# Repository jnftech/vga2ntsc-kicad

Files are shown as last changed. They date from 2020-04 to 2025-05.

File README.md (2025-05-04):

# RetroTINK VGA2NTSC - KiCad Conversion/Modification

This is a modified version of Mike Chi's VGA2NTSC v1.1.
The first goal was to convert the original Altium source files to KiCad - a free and open source tool - as not everyone has access to Altium. Secondly, most footprints have been swapped to make the board more DIY friendly - for example swapping 0402 components (difficult to solder by hand) with 0805 or larger.

As of April 2023, the version shown here is a "final" version (meaning I will no longer make further improvements) that I completed in mid-2021 and only now finally publishing to Github. The changes between the Old version (2020/04/20, archived in the "_Old" folder) and this version are outlined below. 

<p align="center">
  
  
</p>

### Goals:
- Convert original Altium project to KiCad
- Use 0805 footprints instead of smaller packages
- Keep location of jacks and mounting holes in the same locations
- Keep circuit identical to original schematics
- Adjust vertical board size slightly to fit within 100x100mm size limit for cheap boards with many popular PCB fabs
- Add a footprint for a DC barrel jack instead of USB power (either-or can be used in the same spot). Warning has been added to the board denoting 5V power only
- Modified power distribution rail using bottom layer of board
- Relocated clock section to minimize routing near other signals or underneath video amp
- Minimized the use of vias for signal traces where possible.
- More KiCad practice for me
- Finally try to publish something on GitHub (first repo!)

### Changed from 2020/04/20 version:
- Tided up board outline and removed some workaround circular holes in some footprints.
- Added selectable HV/CSYNC switch
- AC coupling on the RGB lines of Scart Output (C22 - C25). The original design left these DC coupled. DC coupling can still be achieved by simply jumping the capacitor pads (for example using larger 0 ohm resistors, like 1206 or 1812)
- There are a few extra "tinkerer/advanced" pins (see below) but there are two solder jumpers implemented to make use of these.

### TL;DR on the two solder jumpers (JP1 and JP2)
- Close these both with solder if you want just NTSC video output. If you are not sure, then just close them both.

### Advanced/Tinkerer features (ignore this if you want just NTSC output with the standard board setup)
- Added a way to bypass the on-board clock circuit. This might be handy for someone wanting to get PAL output from the board by feeding in an external clock signal (EXT_CLOCK). See warning note below.
  - Note that JP1 must be closed with solder for "normal" NTSC operation using the onboard clock circuit. Leave JP1 open to feed external clock signal.
- Added pads for manipulating the NTSC/PAL pin on the AD725 if desired. Switching to PAL would require a different clock signal (see above, and see warning note below).
  - Close JP2 with solder for "normal" NTSC operation. (Just pulls the AD's STND pin high)
  - Leave JP2 open if you want the ability to toggle the mode.
  - WARNING: The three pins in the middle of the board (labeled "NTSC", "", and "PAL" on the underside) are there to implement a toggle. However the "NTSC" and "PAL" pins are just VCC and GND respectively, with the center pin being connected to the AD725's STND pin (which must be pulled either HIGH for NTSC, or LOW for PAL). As I did not have the foresight to think that through, there are no pullup/pulldown resistors. In other words DO NOT SHORT THE NTSC AND PAL PINS TOGETHER, and dont use MBB-style switches to toggle between.
- Added a YTRAP pad for feeding an external YTRAP circuit to the AD725.

### Notes:

<span style="color: red;">This board and circuit, as depicted in this repository, will only deliver an NTSC signal (hence the name VGA2NTSC).
Presence of the aforementioned extra pins (jumpers, clock and NTSC/PAL pins) do not indicate that this board natively supports PAL or any standard other than NTSC.
Those options are for advanced users/tinkerers that are prepard to supply the appropriate clock signal to the board to support other standards.</span>

The board design uses vias-in-pads. This can be a problem for some fabs. JLCPCB (at least with default HASL plating) and OSHpark dont seem to have an issue with this, but some fabs might depending on how they plate the pads. You may need to adjust the locations of the vias and add a couple traces to compensate, should you run into this situation.

### Tools used for conversion:
- Altium2Kicad https://github.com/thesourcerer8/altium2kicad
- Tracespace View (conversion of original Gerbers to SVG for reference and silkscreen adaptations - Alitum2Kicad doesn’t translate original fonts/graphics) https://tracespace.io/view/
- KiCad 5.1.8 https://www.kicad.org/
- Inkscape https://inkscape.org/

<p align="center">
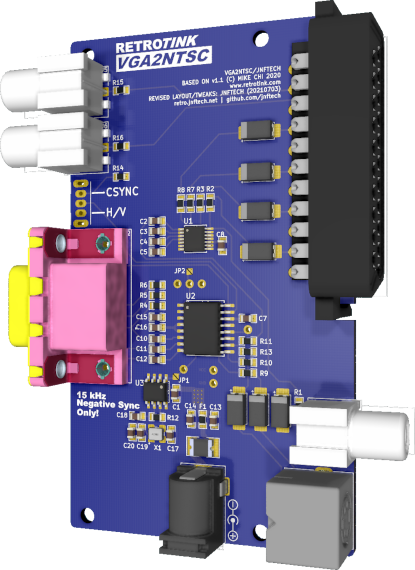
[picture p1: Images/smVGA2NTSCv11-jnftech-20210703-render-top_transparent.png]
<br />
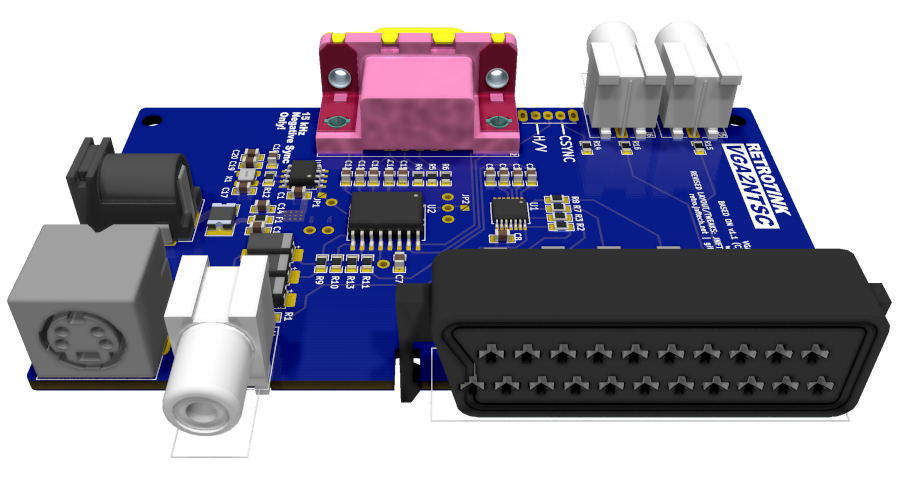
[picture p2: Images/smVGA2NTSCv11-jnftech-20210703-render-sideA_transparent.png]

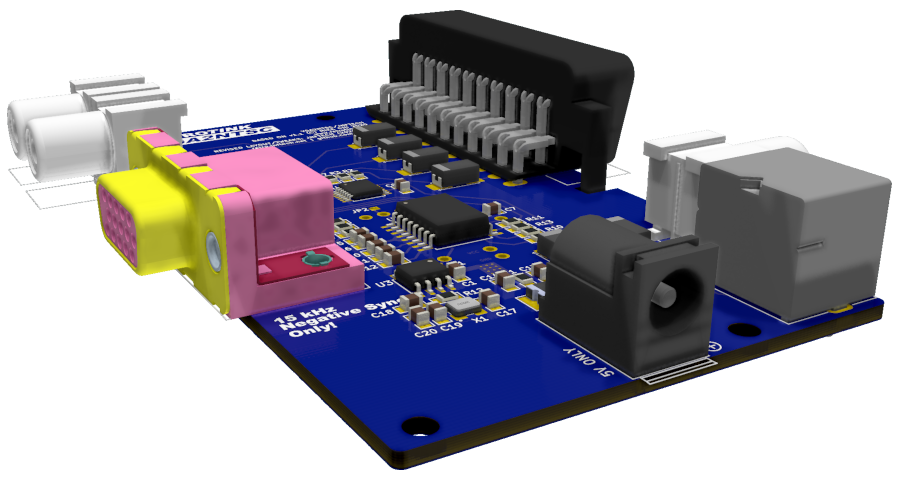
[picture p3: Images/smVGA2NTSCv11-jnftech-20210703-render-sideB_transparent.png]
<br />
</p>

This derivative work maintains the same source license as the original board.
https://www.retrotink.com/post/vga2ntsc-released

### “Mike Chi” License:
(From https://www.retrotink.com/post/vga2ntsc-released)

```
License
The materials are released under the terms below. I don't have time for pedantic nonsense or legal theory and like to keep things simple. I call this the 'Mike Chi' license.

- For each project, at my sole discretion, I may release whatever sources, to whatever level of abstraction, that I deem appropriate. Additional information/materials may be released on a scheduled determined at my sole discretion.
- You may modify, use or adapt any or all portions of the released material for any purpose you wish, including sale.
- The exception is that the files may not be used for commercial activities by entities, determined at my sole discretion, that have a history of violating intellectual property rights or licenses.
- If these materials were helpful and/or of use to you, I only ask that you provide some form of acknowledgment that you feel is fair.
- I'd also love to hear about how you're using it!
- If you re-distribute the material in a substantially unaltered form, please include this notice.
- NO WARRANTY EXPRESSED OR IMPLIED. WE TAKE ABSOLUTELY NO RESPONSIBILITY FOR WHAT MAY OCCUR FROM USAGE OF THE FILES.
- WE CANNOT AND WILL NOT OFFER ANY SUPPORT FOR THE USAGE OF THE FILES. IF YOU DO NOT AGREE WITH THESE TERMS THEN DO NOT USE ANY OF THE MATERIALS AND DON'T COMPLAIN.
```

https://www.retrotink.com/

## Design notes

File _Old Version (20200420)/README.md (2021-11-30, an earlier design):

# RetroTINK VGA2NTSC - KiCad Conversion/Modification

This is a modified version of Mike Chi's VGA2NTSC v1.1.
The first goal was to convert the original Altium source files to KiCad - a free and open source tool - as not everyone has access to Altium. Secondly, most footprints have been swapped to make the board more DIY friendly - for example swapping 0402 components (difficult to solder by hand) with 0805 or larger.

<p align="center">
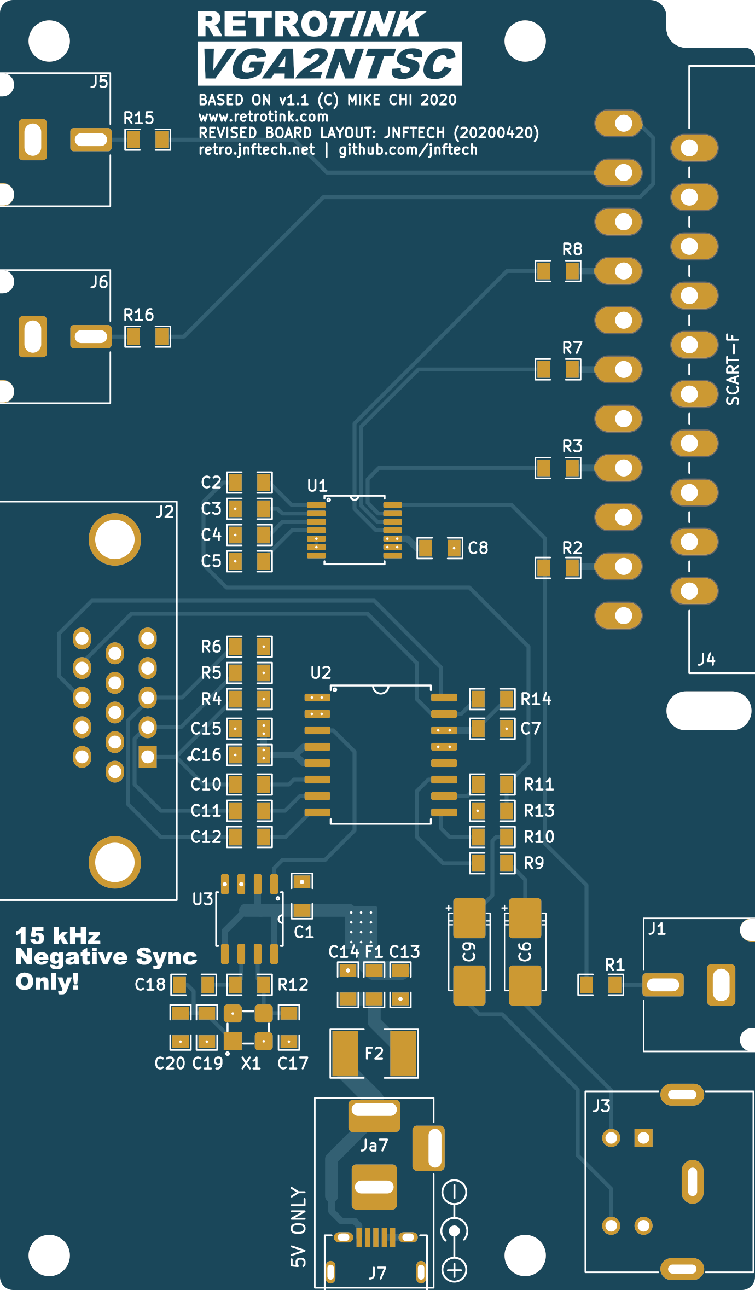
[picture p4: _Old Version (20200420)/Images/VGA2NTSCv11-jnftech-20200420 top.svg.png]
  
</p>

### Goals:
- Convert original Altium project to KiCad
- Use 0805 footprints instead of smaller packages
- Keep location of jacks and mounting holes in the same locations
- Keep circuit identical to original schematics
- Adjust vertical board size slightly to fit within 100x100mm size limit for cheap boards with many popular PCB fabs
- Add a footprint for a DC barrel jack instead of USB power (either-or can be used in the same spot). Warning has been added to the board denoting 5V power only
- Modified power distribution rail using bottom layer of board
- Relocated clock section to minimize routing near other signals or underneath video amp
- Minimized the use of vias for signal traces where possible.
- More KiCad practice for me
- Finally try to publish something on GitHub (first repo!)

### Todo:
- Tidy up board outline. Kicad doesnt play well with Edge.Cuts in footprints when they overlap the board outline, so the circular drills used on the SCART and RCJ-4xx footprints are a workaround.
- Add selectable HV/CSYNC switch
- Add additional clock circuit and switch for PAL mode
- Look for other improvements based on AD725 datasheet information
- (Maybe) version with SCART and/or XRGB-style 8-pin MiniDIN Input  
  
Some of these tweaks are on a test version that is being fabbed by JLCPCB now.

### Notes:
- The board design uses vias-in-pads. This can be a problem for some fabs. JLCPCB (at least with default HASL plating) and OSHpark dont seem to have an issue with this, but some fabs might depending on how they plate the pads. You may need to adjust the locations of the vias and add a couple traces to compensate, should you run into this situation.

### Tools used for conversion:
- Altium2Kicad https://github.com/thesourcerer8/altium2kicad
- Tracespace View (conversion of original Gerbers to SVG for reference and silkscreen adaptations - Alitum2Kicad doesn’t translate original fonts/graphics) https://tracespace.io/view/
- KiCad 5.1.5 https://www.kicad.org/
- Inkscape https://inkscape.org/

<p align="center">
<br />
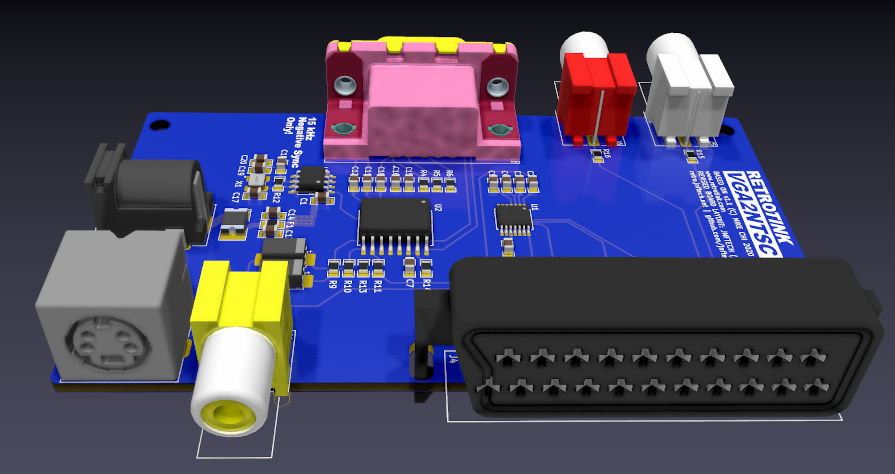
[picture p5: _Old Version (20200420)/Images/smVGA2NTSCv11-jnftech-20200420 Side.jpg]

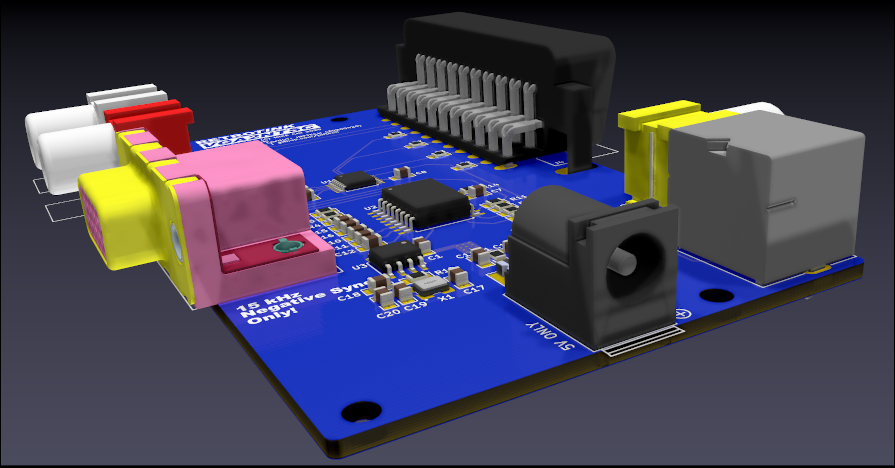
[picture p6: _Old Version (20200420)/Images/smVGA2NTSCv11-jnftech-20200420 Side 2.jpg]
<br />
</p>

This derivative work maintains the same source license as the original board.
https://www.retrotink.com/post/vga2ntsc-released

### “Mike Chi” License:
(From https://www.retrotink.com/post/vga2ntsc-released)

```
License
The materials are released under the terms below. I don't have time for pedantic nonsense or legal theory and like to keep things simple. I call this the 'Mike Chi' license.

- For each project, at my sole discretion, I may release whatever sources, to whatever level of abstraction, that I deem appropriate. Additional information/materials may be released on a scheduled determined at my sole discretion.
- You may modify, use or adapt any or all portions of the released material for any purpose you wish, including sale.
- The exception is that the files may not be used for commercial activities by entities, determined at my sole discretion, that have a history of violating intellectual property rights or licenses.
- If these materials were helpful and/or of use to you, I only ask that you provide some form of acknowledgment that you feel is fair.
- I'd also love to hear about how you're using it!
- If you re-distribute the material in a substantially unaltered form, please include this notice.
- NO WARRANTY EXPRESSED OR IMPLIED. WE TAKE ABSOLUTELY NO RESPONSIBILITY FOR WHAT MAY OCCUR FROM USAGE OF THE FILES.
- WE CANNOT AND WILL NOT OFFER ANY SUPPORT FOR THE USAGE OF THE FILES. IF YOU DO NOT AGREE WITH THESE TERMS THEN DO NOT USE ANY OF THE MATERIALS AND DON'T COMPLAIN.
```

https://www.retrotink.com/

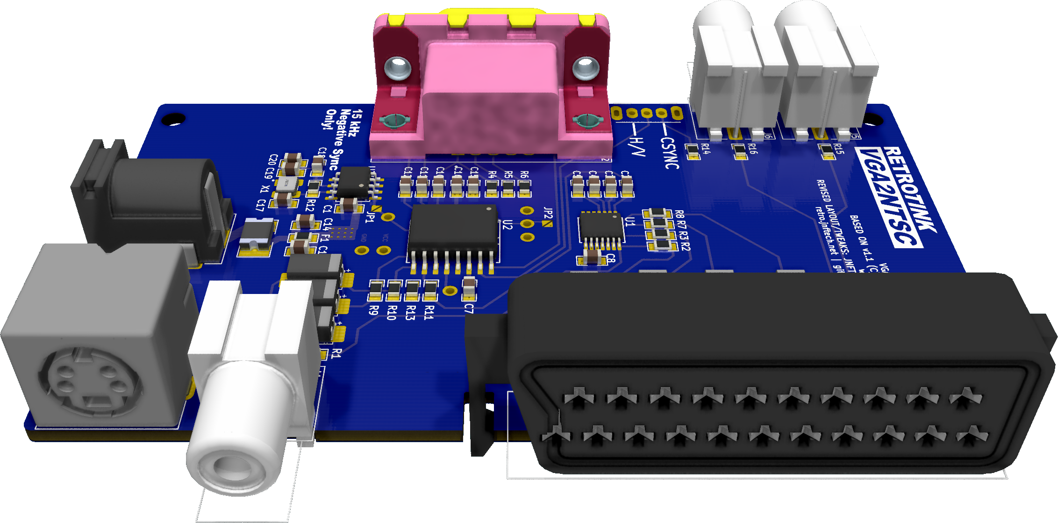
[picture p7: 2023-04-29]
Images/VGA2NTSCv11-jnftech-20210703-render-sideA_transparent.png

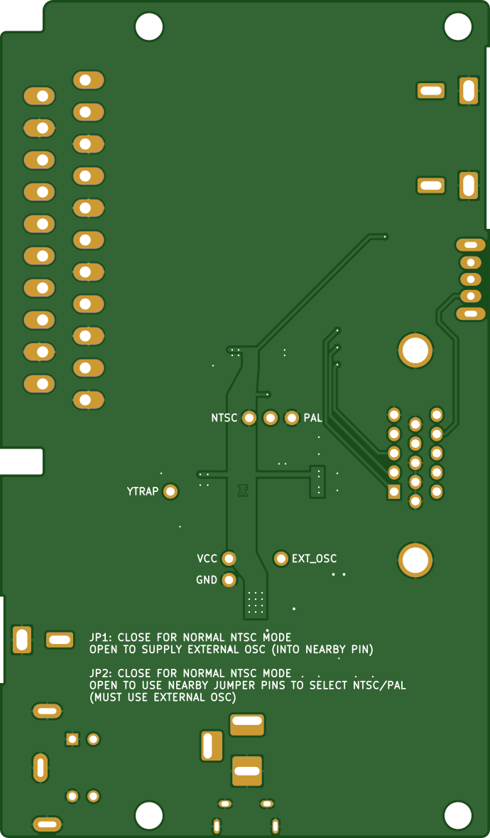
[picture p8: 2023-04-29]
Images/VGA2NTSCv11-jnftech-20210703-gerber-bottom.png

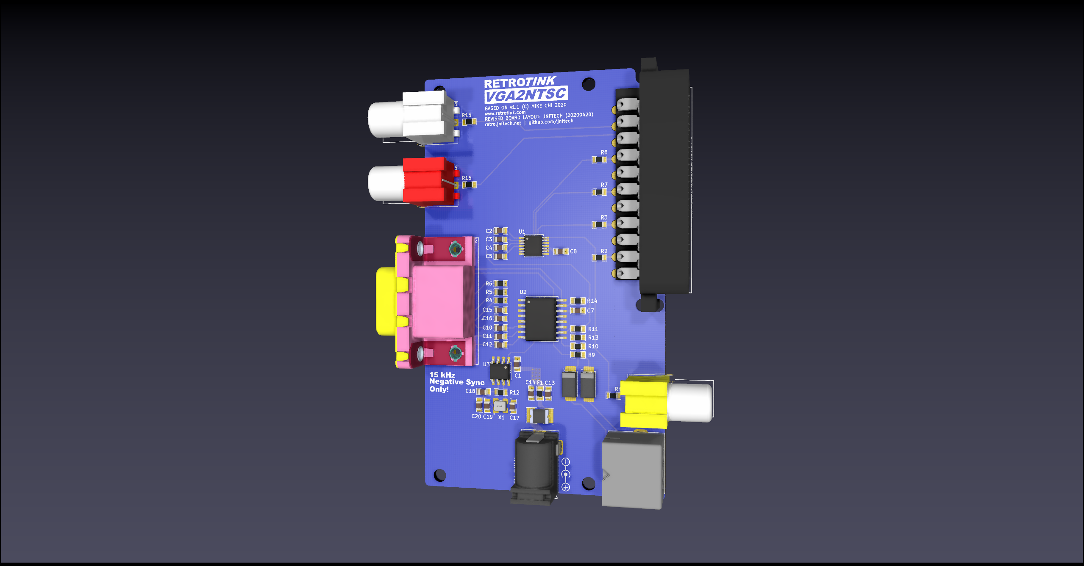
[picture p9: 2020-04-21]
Images/VGA2NTSCv11-jnftech-20200420 Top.png

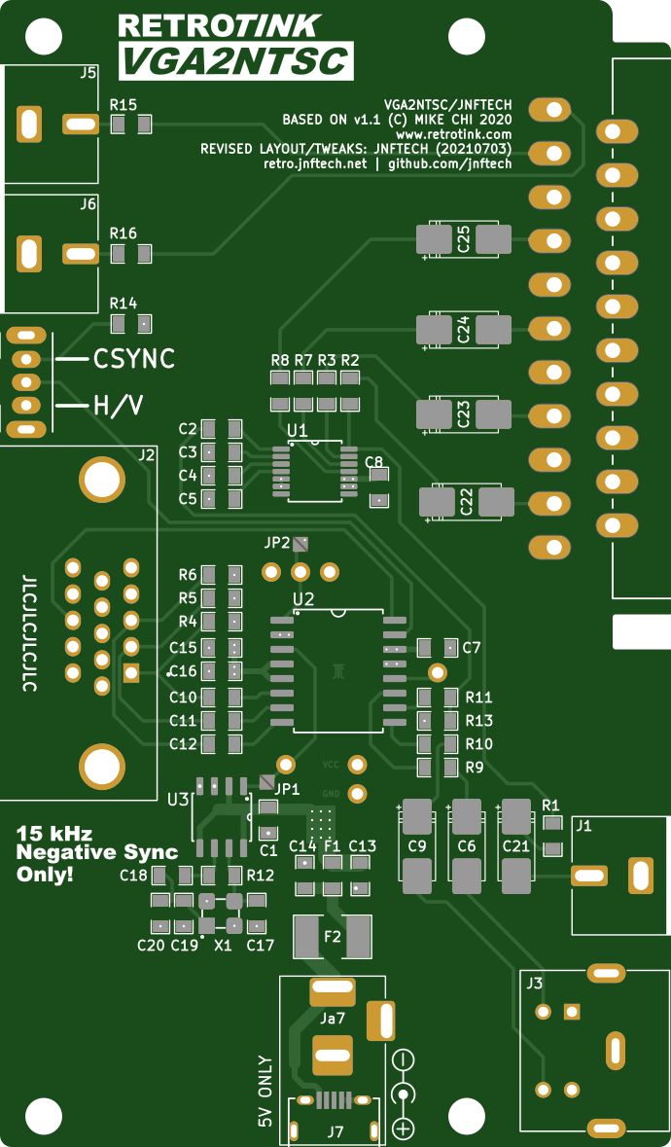
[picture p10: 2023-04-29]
Images/VGA2NTSCv11-jnftech-20210703-gerber-top.png

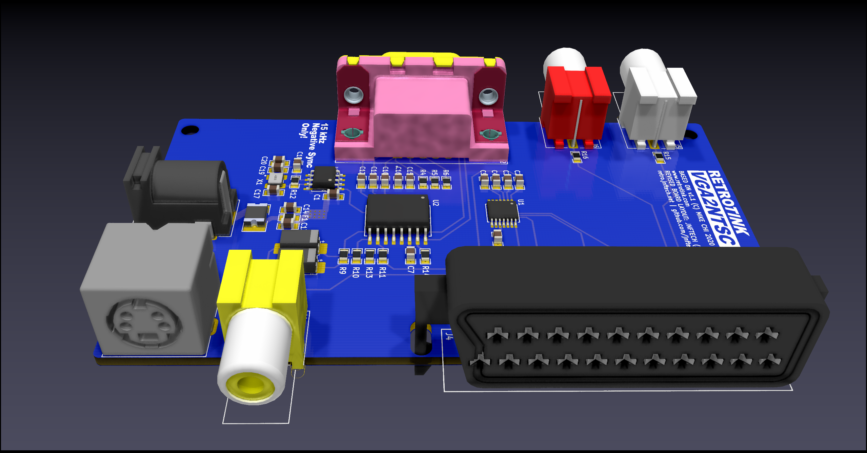
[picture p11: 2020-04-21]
Images/VGA2NTSCv11-jnftech-20200420 Side.png

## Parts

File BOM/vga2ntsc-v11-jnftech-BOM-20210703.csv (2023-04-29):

Designator | ManufacturerPartNumber | DigiKey | LCSC | Quantity | Value | Size | Voltage | Tolerance | Comments | Substitute
C1, C2, C3, C4, C5, C7, C8, C10, C11, C12, C16 | CL21B104JBCNNNC | 1276-1090-1-ND | C62912 | 11 | 100nf | 0805 | >=16v | 5% | Ceramic Cap X7R
C6, C9, C21, C22, C23, C24, C25 | TAJC227M006RNJ | 478-11057-1-ND | C132271 | 7 | 220uf | CASE-C | 6.3V | 10% | Tantalum Cap | Any Case C 220uf =>6.3v
C13, C14, C15 | GRM21BR61C106KE15K | 490-6473-1-ND | C408141 | 3 | 10uf | 0805 | 10v | 10% | X5R | CL21A106KOQNNNE
C17 | CL21C180JBANNNC | 1276-1107-1-ND | C170109 | 1 | 18pf | 0805 | 50v | 5% | C0G
C18, C19, C20 | CL21C470JBANNNC | 1276-1156-1-ND | C14857 | 3 | 47PF | 0805 | 50V | 5% | C0G
F1 | BLM21PG221SN1D | 490-1054-1-ND | C85840 | 1 | 100mOhm | 0805 | 2A | 220R @100Mhz | Ferrite Bead
F2 | 1812L050/30 | F4159CT-ND | C151168 | 1 | 1A | 1812 | 30V |  | Fuse
J1 | RCJ-044 | CP-1421-ND | N/A | 1 |  |  |  |  | RCA Jack Yellow
J2 | ICD15S13E4GX00LF | 609-5181-ND | C75754 | 1 |  |  |  |  | VGA Dsub | (LCSC) DS1038-15FBNSiA74-0CC
J3 | MD-40SM | CP-2240-ND | N/A | 1 |  |  |  |  | S-Video
J4 | SCART | Find it on Aliexpress? | N/A | 1 |  |  |  |  | SCART Female
J7 | 10118194-0001LF | 609-4618-1-ND | C132563 | 1 |  |  |  |  | USB Connector
J7 (Alternate) | PJ-002A | CP-002A-ND | C319099 | 1 |  |  |  |  | DC Barrel (Use instead of USB Power input if desired) | (LCSC) XKB DC-005-2.5A-2.0
J5 | RCJ-043 | CP-1420-ND | N/A | 1 |  |  |  |  | RCA Jack White
J6 | RCJ-042 | CP-1419-ND | N/A | 1 |  |  |  |  | RCA Jack Red
R1, R2, R3, R4, R5, R6, R7, R8, R9, R10 | RC0805FR-0775RL | 311-75.0CRCT-ND | C141697 | 10 | 75R | 0805 |  | 1% | Resistor
R11, R13 | RC0805FR-071KL | 311-1.00KCRCT-ND | C95781 | 2 | 1K | 0805 |  | 1% | Resistor
R12 | RC0805FR-071ML | 311-1.00MCRCT-ND | C107700 | 1 | 1M | 0805 |  | 1% | Resistor
R14 | RC0805FR-074K7L | 311-4.70KCRCT-ND | C60816 | 1 | 4K7 | 0805 |  | 1% | Resistor
R15, R16 | RC0805FR-0749R9L | 311-49.9CRCT-ND | C132320 | 2 | 49R9 | 0805 |  | 1% | Resistor
SW1 | OS102011MA1QS1 | CKN9560-ND | C136722 | 1 |  |  |  |  | CSYNC/HV Switch | (LCSC) HROparts SK-12D02-VG5
U1 | THS7373IPWR | 296-25626-1-ND | N/A | 1 |  |  |  |  | Video Amp
U2 | AD725ARZ | AD725ARZ-ND | N/A | 1 |  |  |  |  | Video Encoder
U3 | 74HC6323AD,112 | 1727-3330-ND | N/A | 1 |  |  |  |  | Binary Counter (Clock)
X1 | ABM8-28.63636MHZ-B2-T | 535-9143-1-ND | N/A | 1 |  |  |  |  | Oscillator

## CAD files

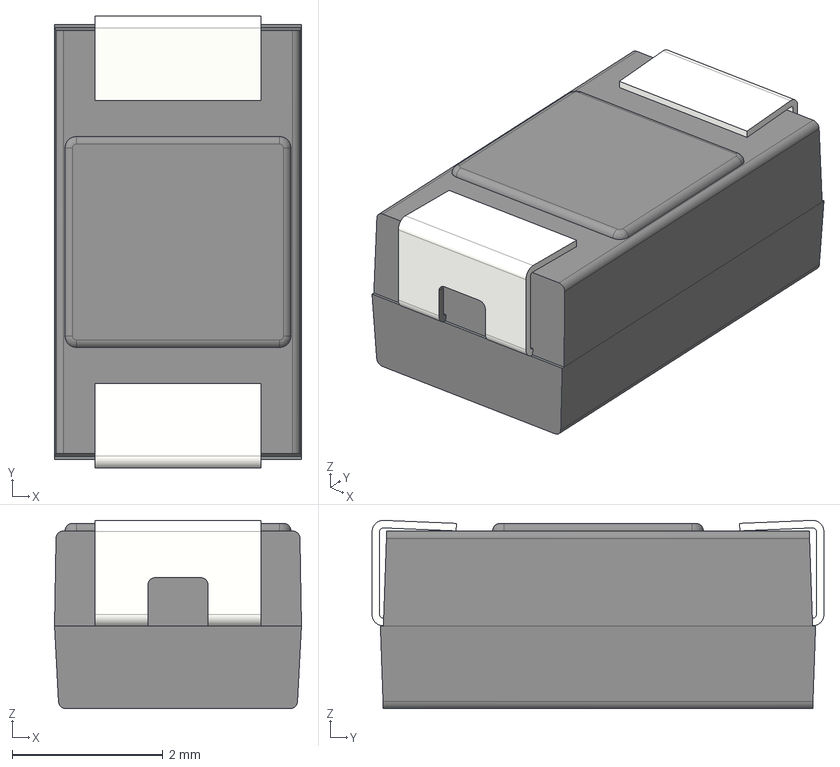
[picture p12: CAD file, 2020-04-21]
wrl/F910J227KCC-F91_C-AVX-TAN.stp
3.28 x 6.00 x 2.50 mm

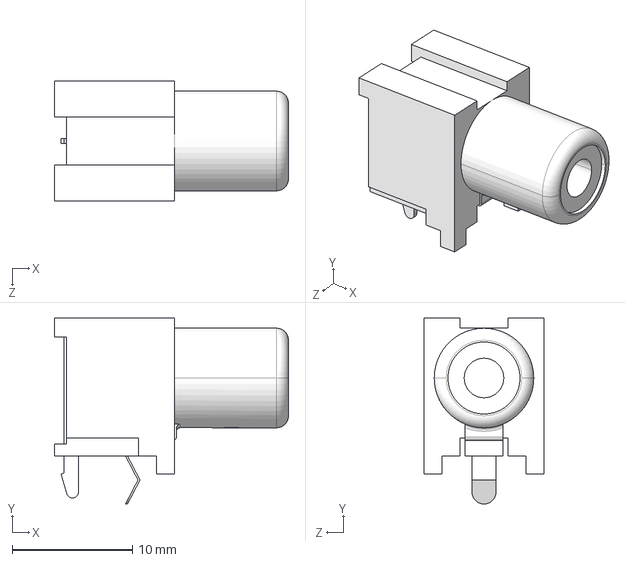
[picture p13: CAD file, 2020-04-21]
wrl/CUI_DEVICES_RCJ-043.step
19.5 x 15.5 x 10.0 mm

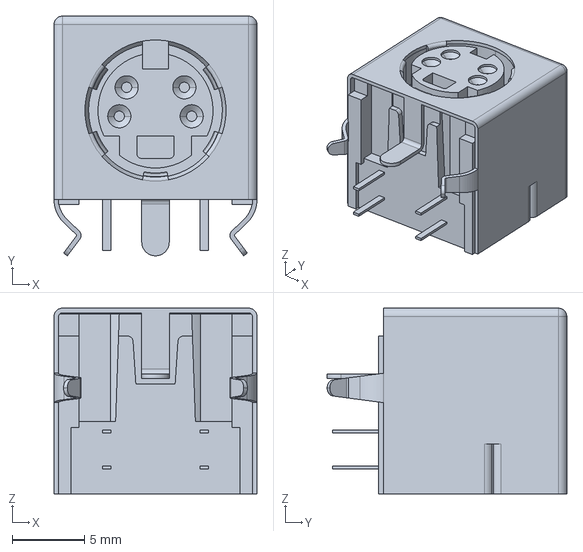
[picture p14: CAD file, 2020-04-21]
wrl/c-5749181-1-a-3d.stp
14.0 x 16.6 x 12.8 mm

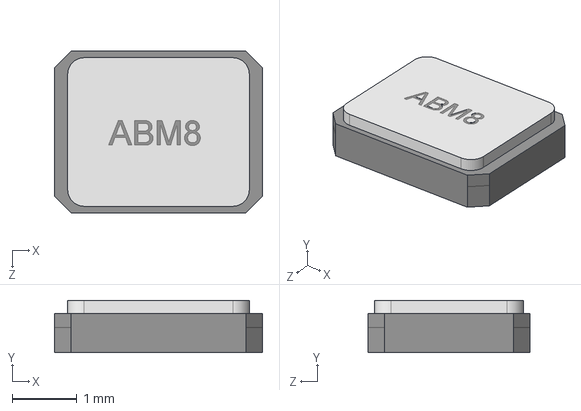
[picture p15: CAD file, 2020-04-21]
wrl/ABM8.STEP
3.20 x 0.8 x 2.49 mm

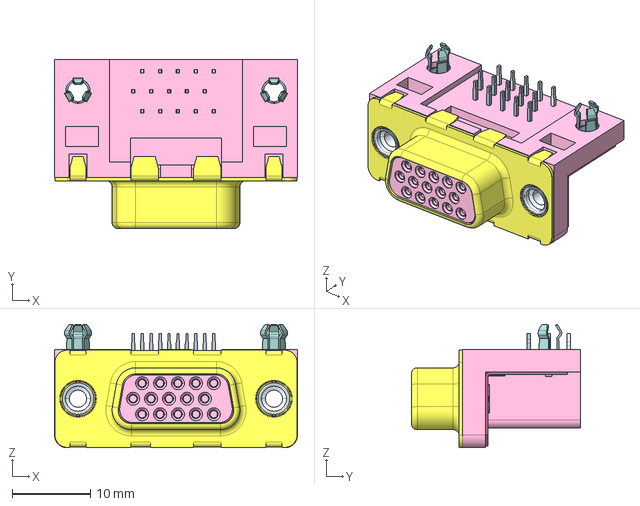
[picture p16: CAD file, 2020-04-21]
wrl/sicd15s13e4gx00lf.stp
31.0 x 21.6 x 15.8 mm

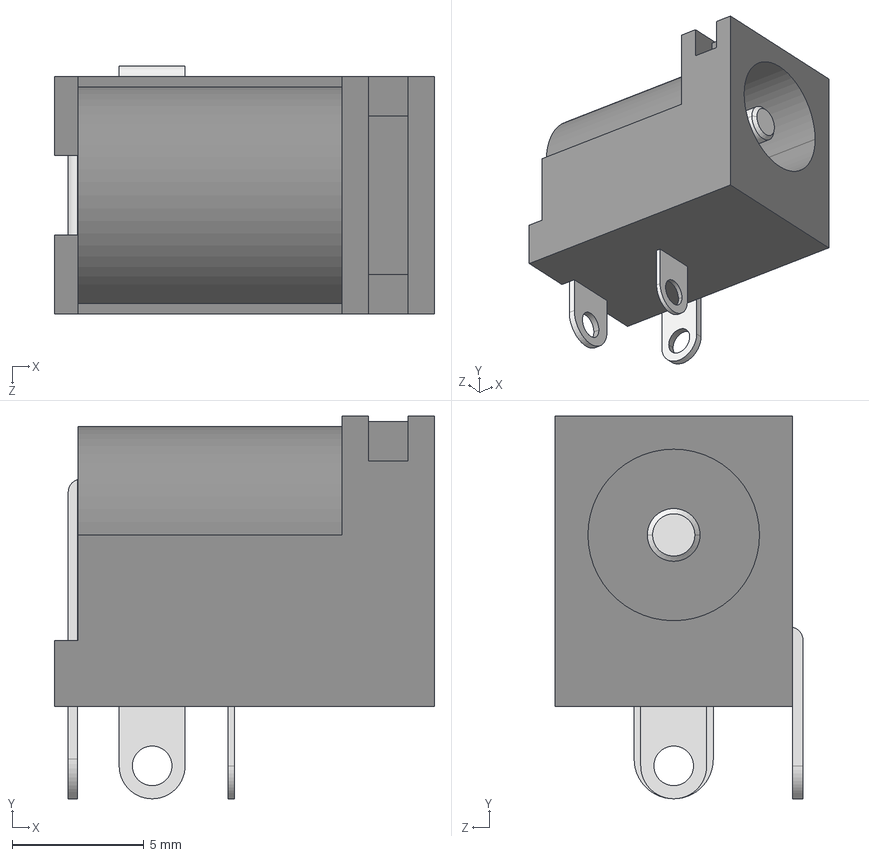
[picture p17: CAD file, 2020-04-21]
wrl/CUI_DEVICES_PJ-002A.step
14.4 x 14.5 x 9.40 mm

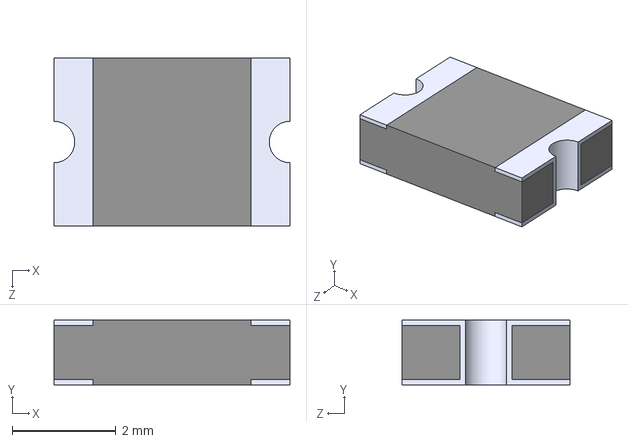
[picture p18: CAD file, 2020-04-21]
wrl/1812L110-16DR--3DModel-STEP-56544.STEP
4.55 x 1.25 x 3.24 mm

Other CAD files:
wrl/CUI_DEVICES_RCJ-044.step
wrl/CUI_DEVICES_RCJ-042.step
_Old Version (20200420)/wrl/CUI_DEVICES_RCJ-044.step
_Old Version (20200420)/wrl/F910J227KCC-F91_C-AVX-TAN.stp
_Old Version (20200420)/wrl/ABM8.STEP
_Old Version (20200420)/wrl/CUI_DEVICES_RCJ-042.step
_Old Version (20200420)/wrl/CUI_DEVICES_RCJ-043.step
_Old Version (20200420)/wrl/sicd15s13e4gx00lf.stp
_Old Version (20200420)/wrl/c-5749181-1-a-3d.stp
_Old Version (20200420)/wrl/CUI_DEVICES_PJ-002A.step
_Old Version (20200420)/wrl/1812L110-16DR--3DModel-STEP-56544.STEP

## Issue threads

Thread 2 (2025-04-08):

PAL mode?

2mg, 2025-04-08:
Is external clock needed for PAL (JP2), or is it enough to close JP1 and open JP2?

Should YTRAP be grounded when using PAL?

jnftech, 2025-04-14:
Hi there,

My apologies, I realize I probably didn't do a great job of explaining the why behind those jumpers and the nearby holes. My original intent was to keep the board NTSC native, but allow expansion to a switchable PAL/NTSC version via a daughter-board, should someone want to design such a thing. In hindsight it probably makes more sense for someone to expand on the original board for that functionality.

First off, YTRAP is always optional. Nothing needs to be done there and you can leave that alone. The hole there is to allow additional circuitry be fed in (described in the AD725 datasheet, and unfortunately I lack the EE and video knowledge to understand it fully).

If your interest is to hard code the board in PAL mode:

- Leave JP2 Open, and manually jump (short wire) the two left-most holes just below the jumper. This pulls the NTSC/PAL pin of the AD725 low for PAL mode (as labeled on the bottom of the board). JP2 is in fact just an easy way to pull this pin high with a solder strap.

The clock is a trickier topic:

- One way: In theory you could find an appropriate crystal to supply the correct clock for PAL mode, and then still close JP1 (which just completes the connection between the AD Clock pin and the output of the clock IC). However a drop in replacement would require a 35.46895Mhz crystal (U3 would then divide this down to the 17.734475Mhz clock the AD chip needs for PAL operation), and I couldn't find a part number that fit the bill in my very brief search. Not saying such a part doesn't exist, but not parts that are stocked at Digikey.
- The other way (without modifying the main board's layout/schematics) would be a separate small daughter-board that could generate the 17.734745Mhz clock via different circuitry and parts. You would leave JP1 open in this case (and probably not bother populating the on board clock parts), and supply the output of this board into the nearby EXT_CLK pin. There are spare VCC and GND pins to supply power to such a board.

I hope that helps answer your question.

2mg, 2025-04-18:
Wait, so if I switch to PAL how you described (JP2 + shorting), it won't be PAL due to lack of a proper crystal (or ext clk)?

Regarding YTRAP, it should provide a clearer picture, no?
But as it is, it needs more circuitry?

jnftech, 2025-05-04:
Correct. The board's existing circuit and components, as designed, will only give you NTSC as is - this is one reason the project is named VGA2NTSC. The clock circuit that feeds the AD725 can only deliver a frequency appropriate for an NTSC color subcarrier. To successfully implement PAL, you need a different clock circuit to deliver the correct frequency for PAL.
The AD725, for whichever video standard you desire, needs the chroma subcarrier frequency*4 supplied to the clock pin. PAL's chroma subcarrier is 4.43361875Mhz - thus you need to feed the clock pin 17.734475Mhz. But the board design as supplied in this repository will not do that.

A note on YTRAP: In theory this can reduce cross-talk between the luma and chroma signals in the composite video output, possibly leading to a better picture. Unfortunately (as I'm no EE) the circuitry is beyond my current knowledge/skillset, so I cant explain what is needed. I believe the datasheet outlines an example circuit and explains the notch filter it implements: https://www.analog.com/media/en/technical-documentation/data-sheets/AD725.pdf (Page 15).
It is worth noting YTRAP affects only composite output. If your goal is S-Video/Y-C, then this pin will have no effect with this output.

Just a quick remind of what's mentioned on the readme: I did not design the original circuit, but simply did some modifications to the board to make it more DIY friendly, with a few "tinkerer" options (like the extra clock and ytrap pins). But the circuit doesn't really deviate from the original, so that's where I left it and moved on. I think I will however take some time to revise the readme as I feel the PAL support may be unclear.

As the design is open source, anyone is welcome to adapt the board to support both standards - perhaps call it VGA2AV instead. But I will leave that to others to take on (I have no PAL hardware to test anyway). There are DFO circuits out there for various consoles that could probably be adapted to do the job.

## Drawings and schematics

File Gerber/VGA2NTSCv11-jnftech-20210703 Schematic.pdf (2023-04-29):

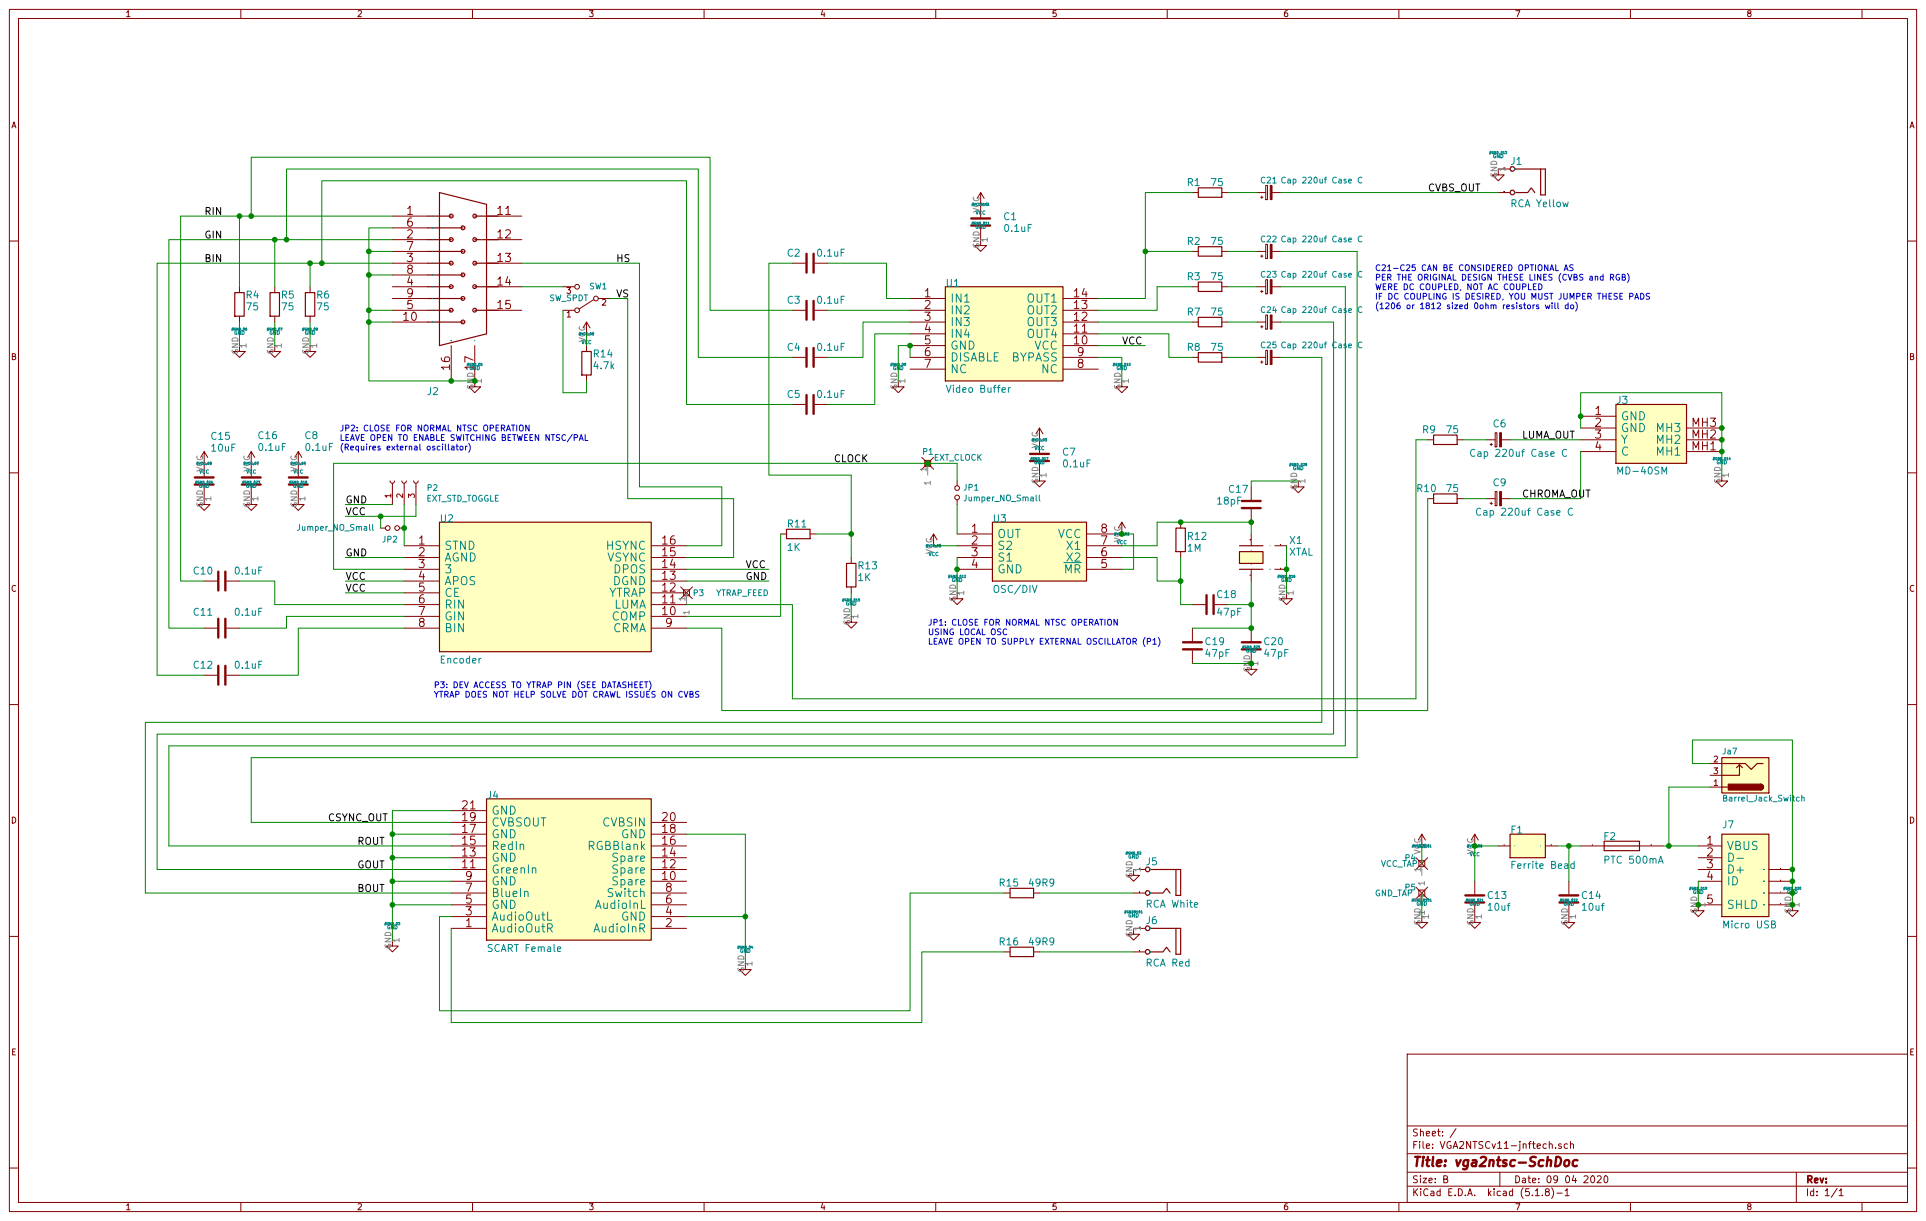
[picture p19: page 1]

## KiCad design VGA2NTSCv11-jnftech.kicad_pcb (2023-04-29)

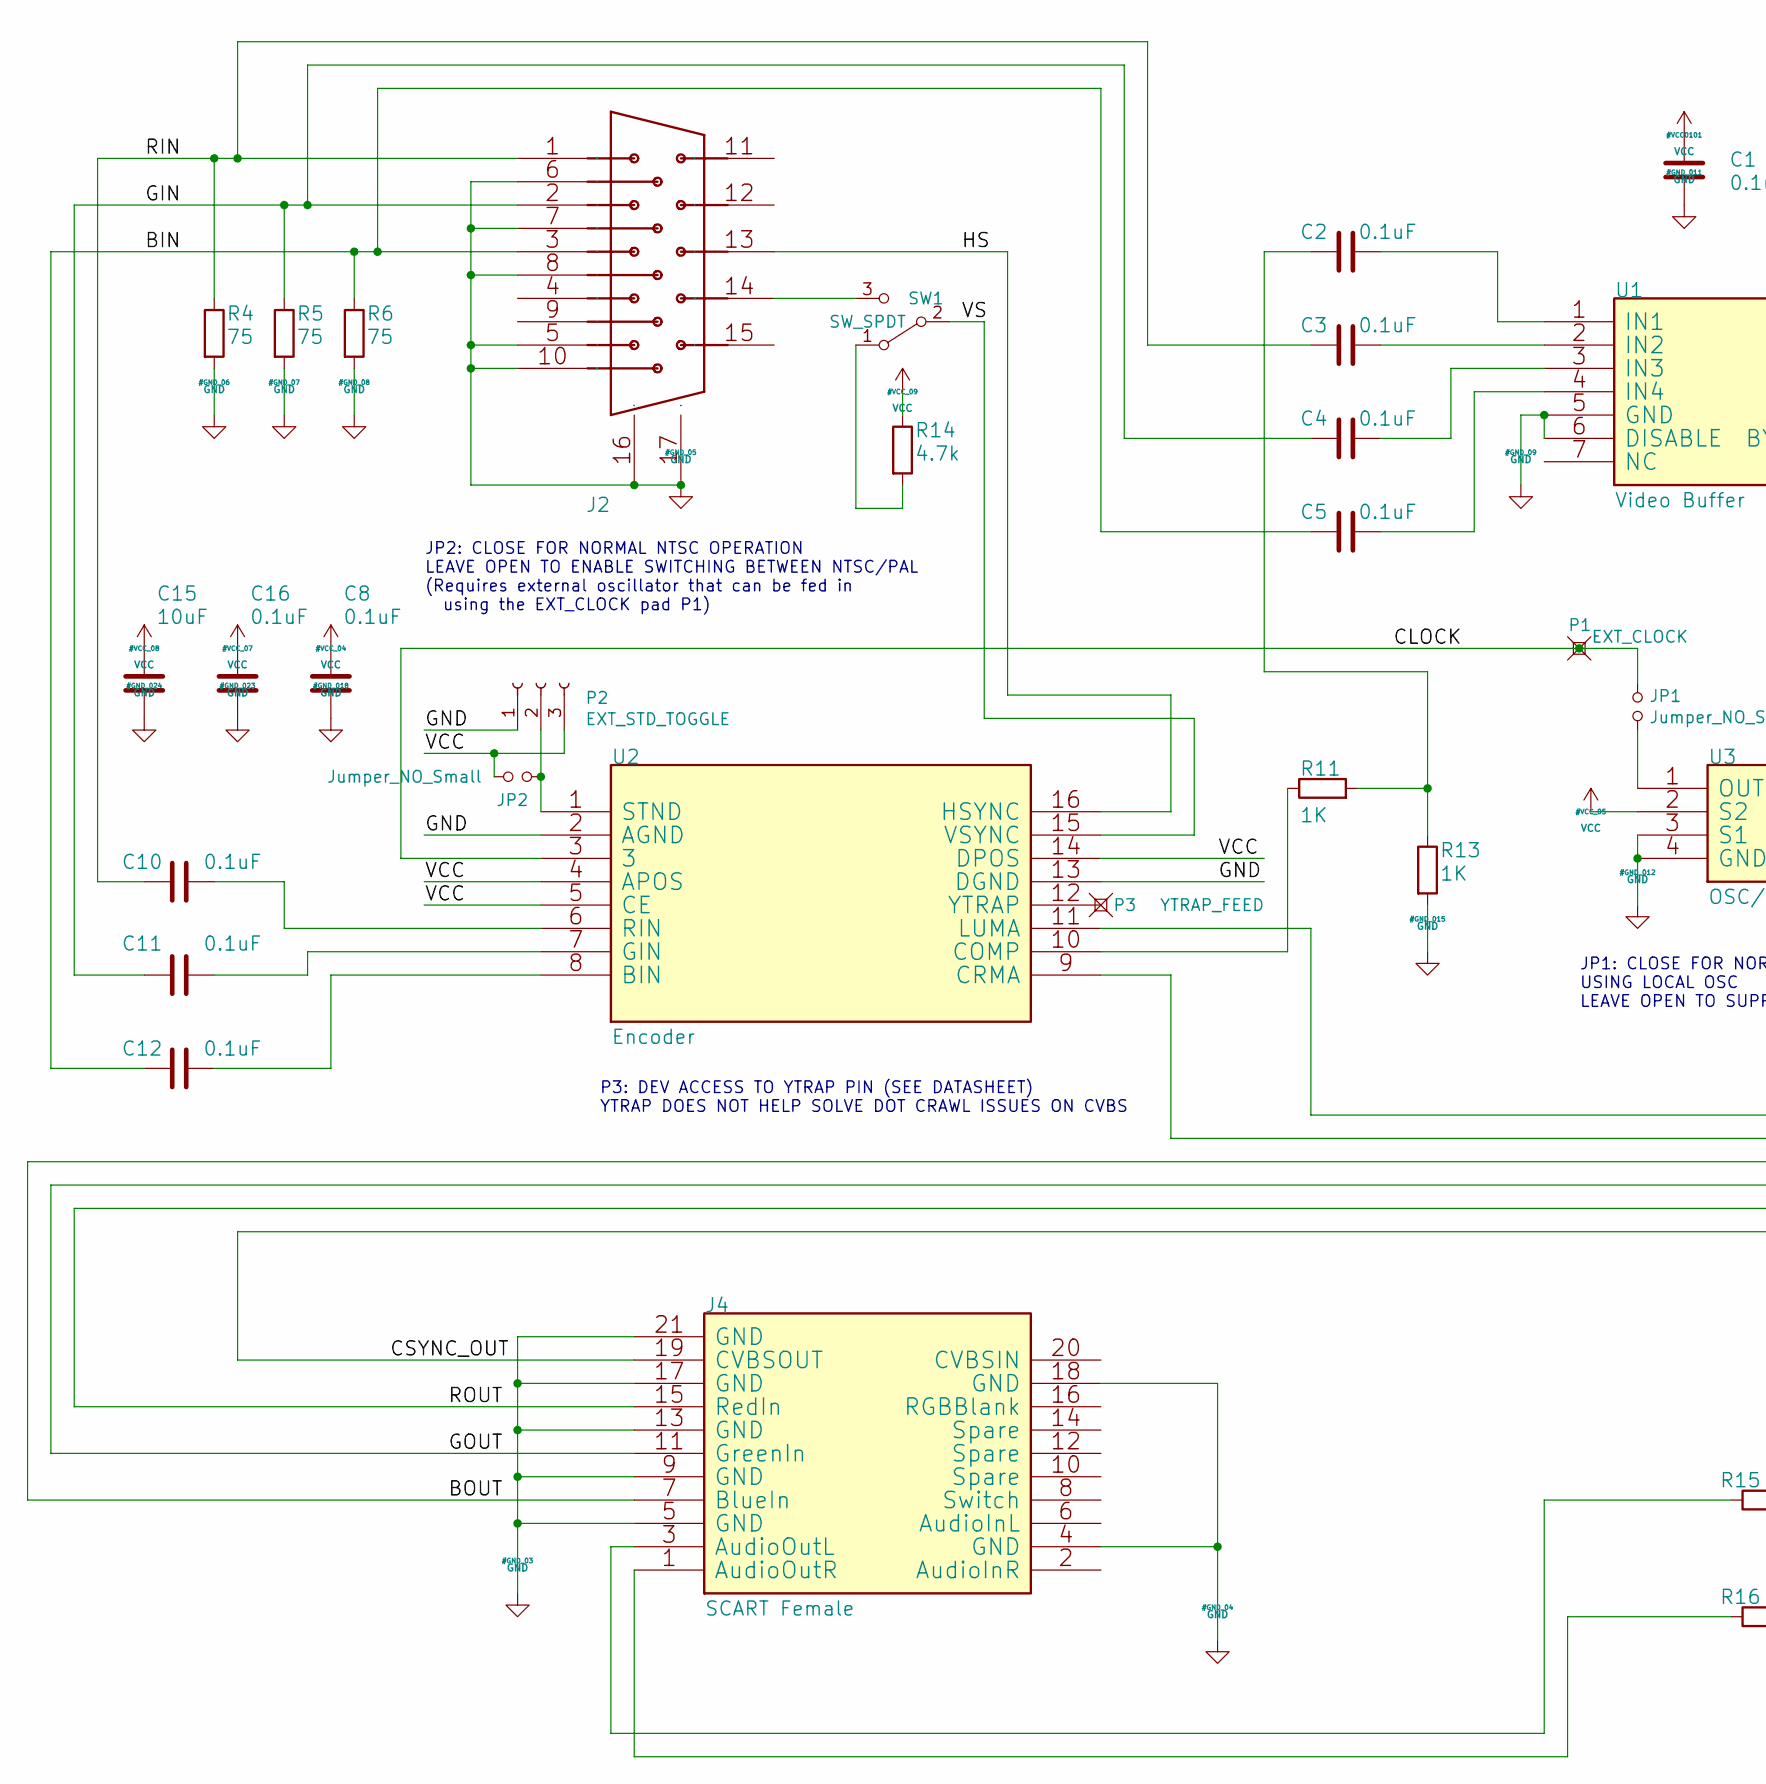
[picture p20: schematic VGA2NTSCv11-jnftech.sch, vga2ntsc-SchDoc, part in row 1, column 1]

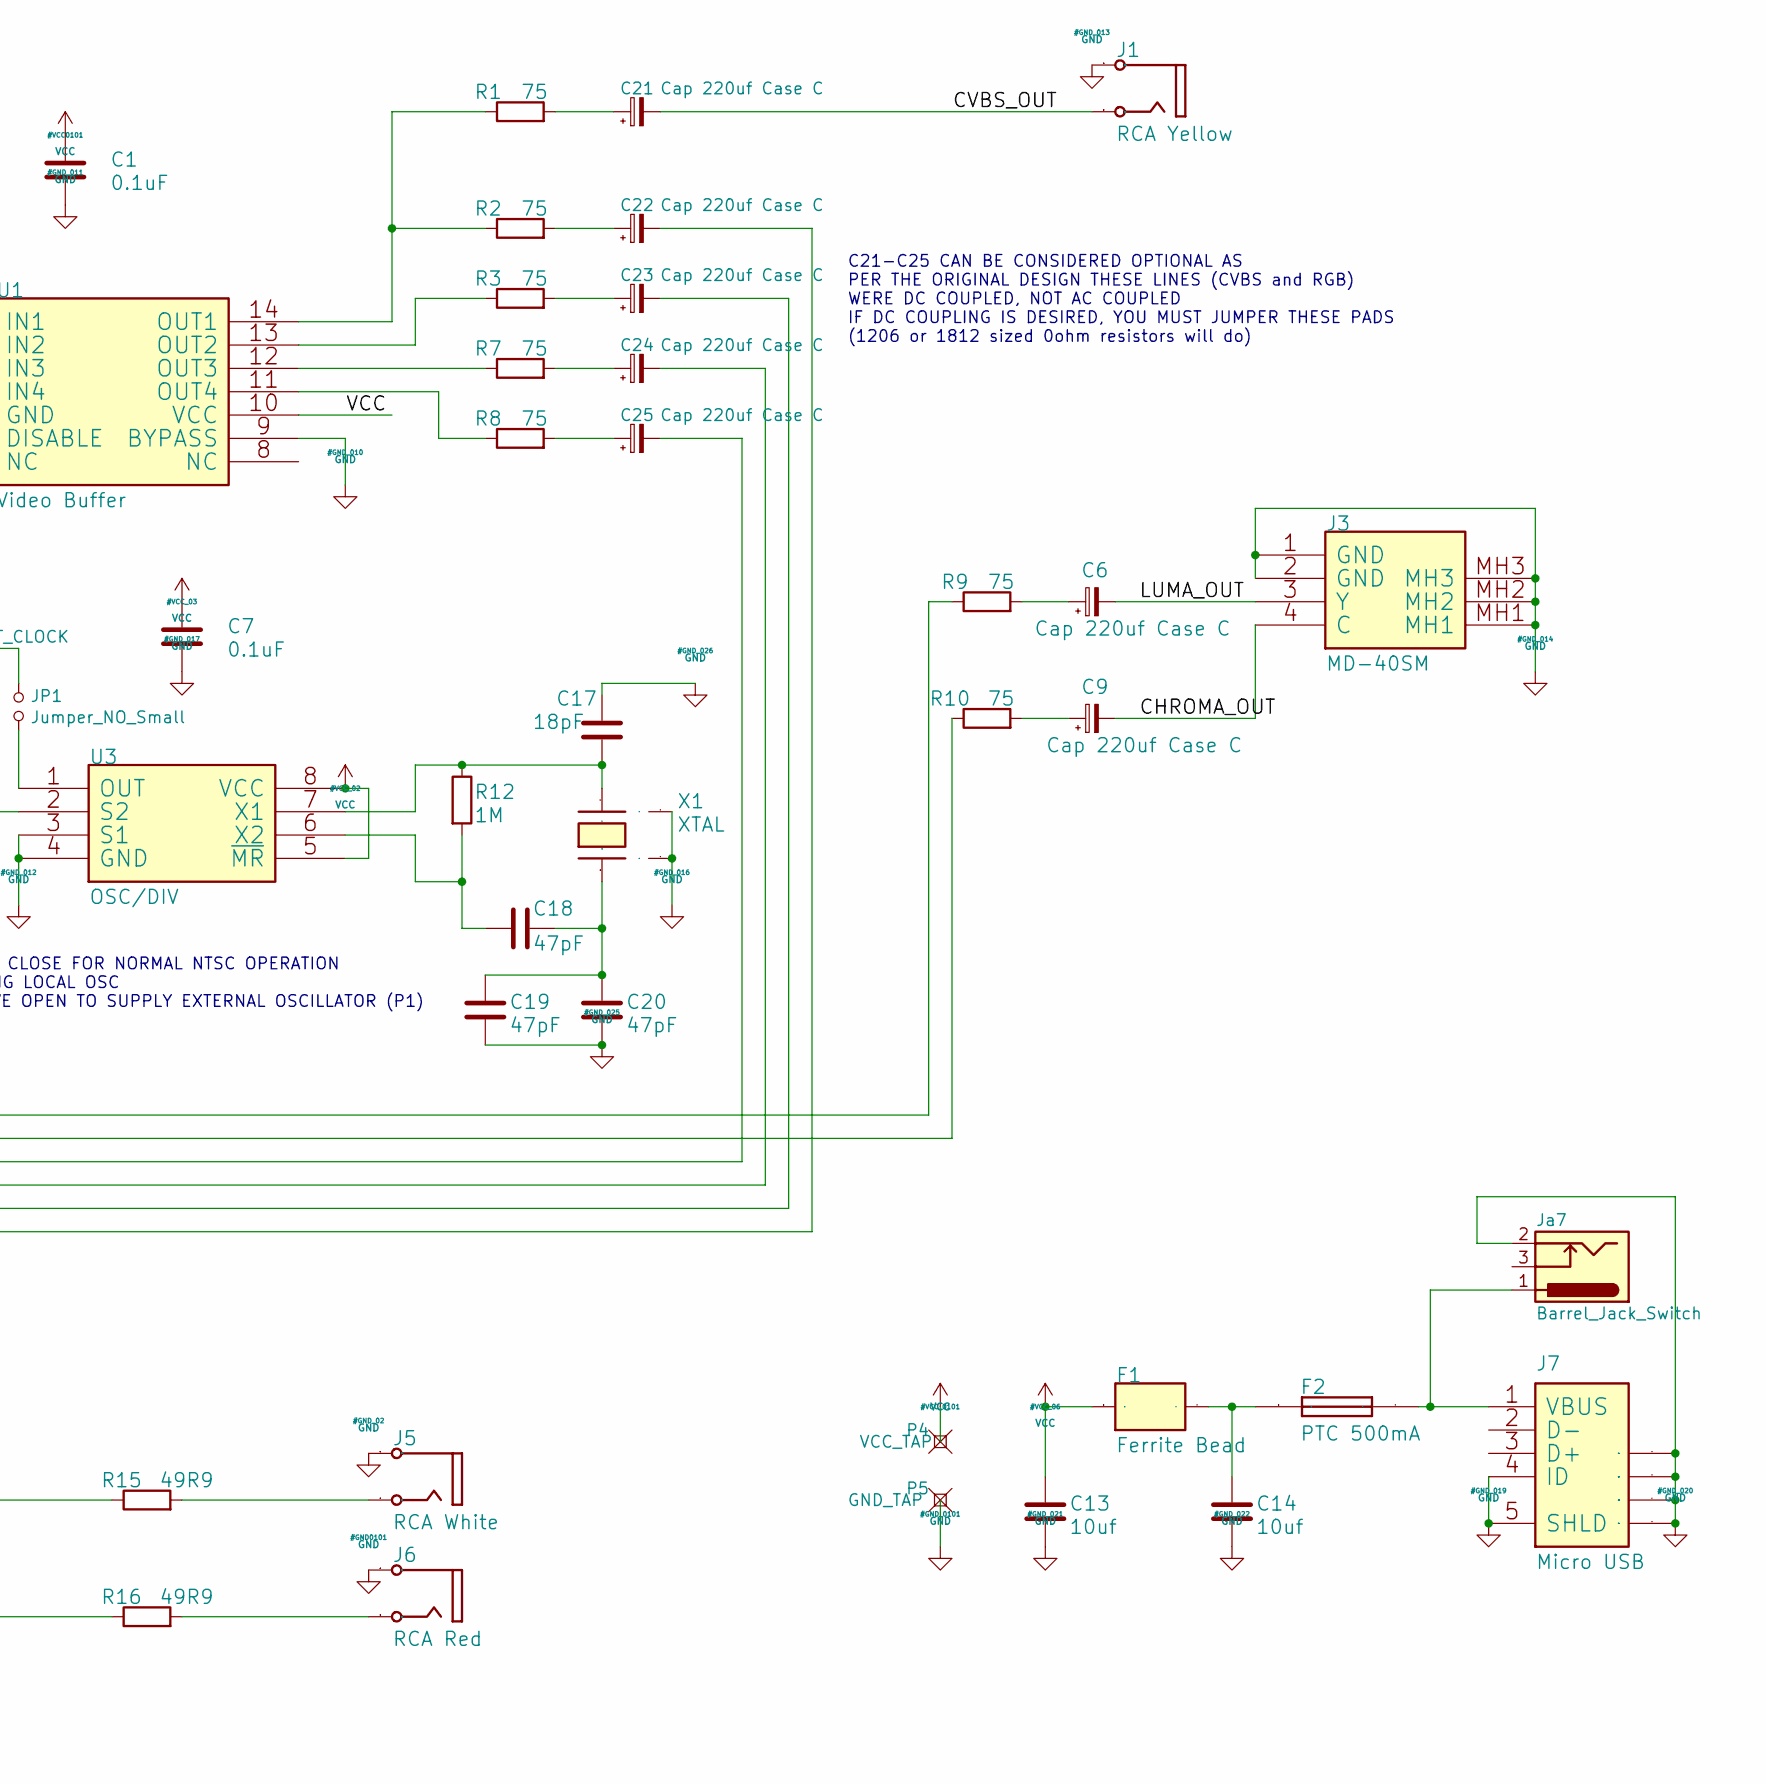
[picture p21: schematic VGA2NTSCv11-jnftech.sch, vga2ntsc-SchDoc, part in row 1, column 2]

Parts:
C1, C2, C3, C4, C5, C7, C8, C10, C11, C12, C16: 0.1uF; R_0805_1mm
C6, C9, C21, C22, C23, C24, C25: Cap 220uf Case C; CP_Tantalum_Case-C_EIA-6032-28_JFT
C13, C14: 10uf; R_0805_1mm
C15: 10uF; R_0805_1mm
C17: 18pF; R_0805_1mm
C18, C19, C20: 47pF; R_0805_1mm
F1: Ferrite Bead; R_0805_1mm
F2: PTC 500mA; R_1812_1206-JFT
J1: RCA Yellow; RCJ-04x_NoHole
J2: AMPHENOL_L77HDE15SD1CH4F_Drill1SizeOval
J3: MD-40SM; CUI_MD-40SM_VGA2NTSC
J4: SCART Female; SCART-F-RA-NoHole
J5: RCA White; RCJ-04x_NoHole
J6: RCA Red; RCJ-04x_NoHole
J7: Micro USB; Connector_MicroUSB_Amp10118194-0001LF
JP1, JP2: Jumper_NO_Small; WirepadJumperSm
Ja7: Barrel_Jack_Switch; BARREL_JACK-JFT
P1: EXT_CLOCK; TH_Hole_One_1mm
P2: EXT_STD_TOGGLE; Pin_Header_Straight_1x03_Pitch2.54mm_NoSilk
P3: YTRAP_FEED; TH_Hole_One_1mm
P4: VCC_TAP; TH_Hole_One_1mm
P5: GND_TAP; TH_Hole_One_1mm
R1, R2, R3, R7, R8, R9, R10: 75; R_0805_1mm
R4, R5, R6: 75; R_0805_1mm; Tolerance 1%
R11, R13: 1K; R_0805_1mm; Tolerance 1%
R12: 1M; R_0805_1mm; Tolerance 1%
R14: 4.7k; R_0805_1mm; Tolerance 5%
R15, R16: 49R9; R_0805_1mm
SW1: SW_SPDT; SW_HRO-SK-12D02_SPDT_Angled
U1: Video Buffer; TSSOP-14_4.4x5mm_Pitch0.65mm-JFT
U2: Encoder; SOIC-16W_7.5x10.3mm_Pitch1.27mm_HS
U3: OSC/DIV; SOIC-8_3.9x4.9mm_Pitch1.27mm-JFT
X1: XTAL; Crystal_4SMD-NL_3.2mmx2.5mm_HandSolder

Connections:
/BIN: C5.1, C12.1, J2.3, R6.1
/BOUT: C25.2, J4.7 (BlueIn)
/CHROMA_OUT: C9.2, J3.4 (C)
/CLOCK: JP1.1, P1.1, U2.3
/CSYNC_OUT: C22.2, J4.19 (CVBSOUT)
/CVBS_OUT: C21.2, J1.2B (Signal)
/GIN: C4.1, C11.1, J2.2, R5.1
/GOUT: C24.2, J4.11 (GreenIn)
/HS: J2.13, U2.16 (HSYNC)
/LUMA_OUT: C6.2, J3.3 (Y)
/RIN: C3.1, C10.1, J2.1, R4.1
/ROUT: C23.2, J4.15 (RedIn)
/VS: SW1.2 (B), U2.15 (VSYNC)
GND: C1.1, C7.1, C8.1, C13.2, C14.2, C15.2, C16.1, C17.1, C19.1, C20.1, J1.1A (Ground), J2.5, J2.6, J2.7, J2.8, J2.10, J2.16, J2.17, J3.1 (GND), J3.2 (GND), J3.MH1, J3.MH2, J3.MH3, J4.4 (GND), J4.5 (GND), J4.9 (GND), J4.13 (GND), J4.17 (GND), J4.18 (GND), J4.21 (GND), J5.1A (Ground), J6.1A (Ground), J7.4 (ID), J7.5 (SHLD), J7.6 (SHLD), J7.7 (SHLD), J7.8 (SHLD), J7.9 (SHLD), Ja7.2, P2.1, P5.1, R4.2, R5.2, R6.2, R13.2, U1.5 (GND), U1.6 (DISABLE), U1.9 (BYPASS), U2.2 (AGND), U2.13 (DGND), U3.3 (S1), U3.4 (GND), X1.2, X1.4
unnamed: C2.1, R11.2, R13.1
unnamed: C2.2, U1.1 (IN1)
unnamed: C3.2, U1.2 (IN2)
unnamed: C4.2, U1.3 (IN3)
unnamed: C5.2, U1.4 (IN4)
unnamed: C6.1, R9.2
unnamed: C9.1, R10.2
unnamed: C10.2, U2.6 (RIN)
unnamed: C11.2, U2.7 (GIN)
unnamed: C12.2, U2.8 (BIN)
unnamed: C14.1, F1.2, F2.1
unnamed: C17.2, R12.1, U3.7 (X1), X1.3
unnamed: C18.1, R12.2, U3.6 (X2)
unnamed: C18.2, C19.2, C20.2, X1.1
unnamed: C21.1, R1.2
unnamed: C22.1, R2.2
unnamed: C23.1, R3.2
unnamed: C24.1, R7.2
unnamed: C25.1, R8.2
unnamed: F2.2, J7.1 (VBUS), Ja7.1
unnamed: J2.14, SW1.3 (C)
unnamed: J4.1 (AudioOutR), R16.1
unnamed: J4.3 (AudioOutL), R15.1
unnamed: J5.2B (Signal), R15.2
unnamed: J6.2B (Signal), R16.2
unnamed: JP1.2, U3.1 (OUT)
unnamed: JP2.1, P2.2, U2.1 (STND)
unnamed: P3.1, U2.12 (YTRAP)
unnamed: R1.1, R2.1, U1.14 (OUT1)
unnamed: R3.1, U1.13 (OUT2)
unnamed: R7.1, U1.12 (OUT3)
unnamed: R8.1, U1.11 (OUT4)
unnamed: R9.1, U2.11 (LUMA)
unnamed: R10.1, U2.9 (CRMA)
unnamed: R11.1, U2.10 (COMP)
unnamed: R14.2, SW1.1 (A)
VCC: C1.2, C7.2, C8.2, C13.1, C15.1, C16.2, F1.1, JP2.2, P2.3, P4.1, R14.1, U1.10 (VCC), U2.4 (APOS), U2.5 (CE), U2.14 (DPOS), U3.2 (S2), U3.5 (~MR), U3.8 (VCC)

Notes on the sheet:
JP1: CLOSE FOR NORMAL NTSC OPERATION USING LOCAL OSC LEAVE OPEN TO SUPPLY EXTERNAL OSCILLATOR (P1)
JP2: CLOSE FOR NORMAL NTSC OPERATION LEAVE OPEN TO ENABLE SWITCHING BETWEEN NTSC/PAL (Requires external oscillator that can be fed in using the EXT_CLOCK pad P1)
C21-C25 CAN BE CONSIDERED OPTIONAL AS PER THE ORIGINAL DESIGN THESE LINES (CVBS and RGB) WERE DC COUPLED, NOT AC COUPLED IF DC COUPLING IS DESIRED, YOU MUST JUMPER THESE PADS (1206 or 1812 sized 0ohm resistors will do)
P3: DEV ACCESS TO YTRAP PIN (SEE DATASHEET) YTRAP DOES NOT HELP SOLVE DOT CRAWL ISSUES ON CVBS

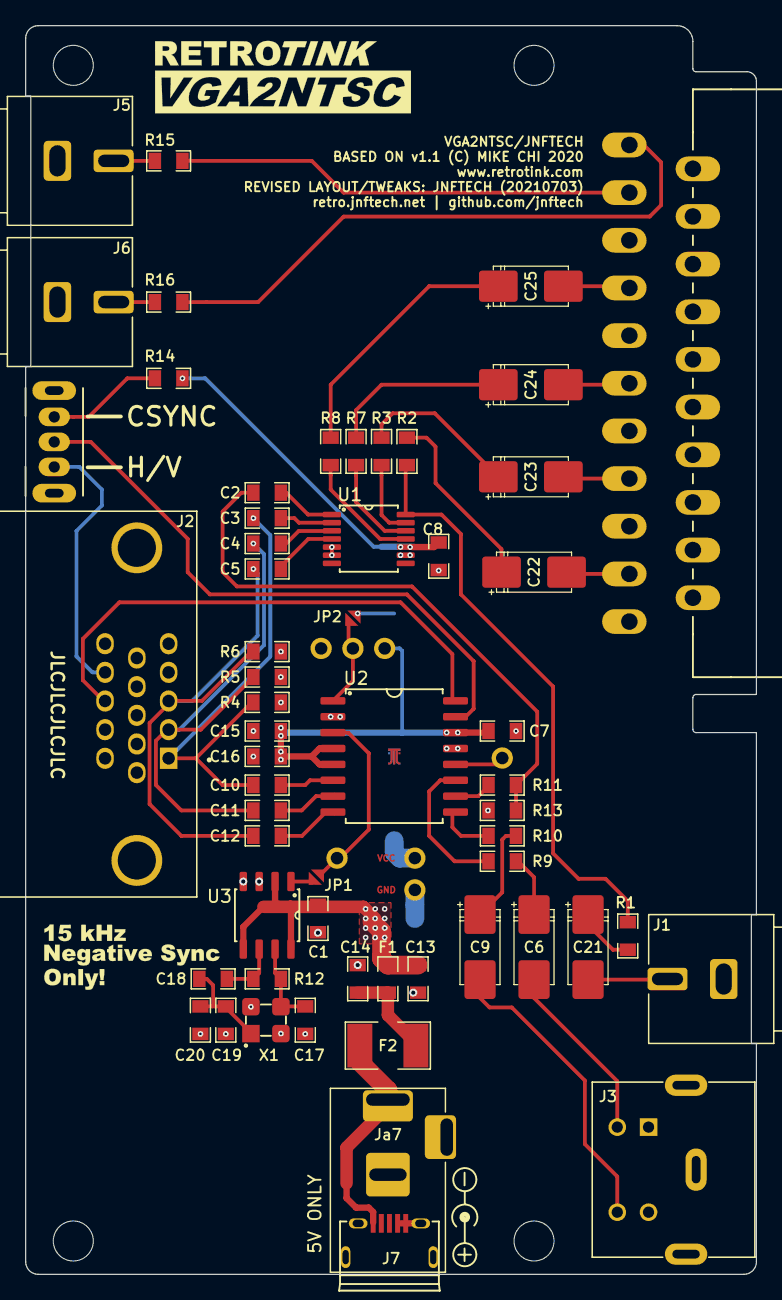
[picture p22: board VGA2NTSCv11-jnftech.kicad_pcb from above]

Board: 2 copper layers, 58.4 x 99.8 mm, 63 parts (0 on the bottom side), 51 nets.

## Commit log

2020-04-21 Cleanup associations between schematic, PCB, and Netlist
    [VGA2NTSCv11-jnftech.kicad_pcb, VGA2NTSCv11-jnftech.sch]
2020-04-22 Fix Polarity silkscreen
    [VGA2NTSCv11-jnftech.kicad_pcb]
2020-05-06 Fix silkscreen errors
    [VGA2NTSCv11-jnftech.kicad_pcb]
2021-11-10 Update README.md
    https://forum.kicad.info/t/warning-avoid-all-links-to-kicad-pcb-org-use-kicad-org/31521
2023-04-29 Updating project to 20210703 version
    [1812L110-16DR--3DModel-STEP-56544.STEP, ABM8.STEP, CUI_DEVICES_PJ-002A.step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]
2023-04-29 Publish BOM
    [vga2ntsc-v11-jnftech-BOM-20210703.csv]
2025-05-04 Update README.md
    Clarifying PAL support and rewording the tinkerer/advanced pin descriptions
